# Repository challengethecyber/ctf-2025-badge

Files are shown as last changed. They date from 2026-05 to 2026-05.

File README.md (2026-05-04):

# ctf-2025-badge
Badge related files for CTC 2025 CTF

badge2025

## Info

- ESP32-C3-Mini
- Micropython
- E-ink display (GDEW0154M10) with UC8151 custom driver for quick partial refreshes
- IO expander (XL9535)
- EEPROM
- SAO

See schematics: [ctc_2025.pdf](hardware/ctc_2025.pdf)

## Credits

 - PCB hw design by [Max Grim](https://github.com/maxgrim).
 - Software by [c3c](https://github.com/c3c) and Max.
 - Display driver based on [GxEPD2](https://github.com/ZinggJM/GxEPD2).

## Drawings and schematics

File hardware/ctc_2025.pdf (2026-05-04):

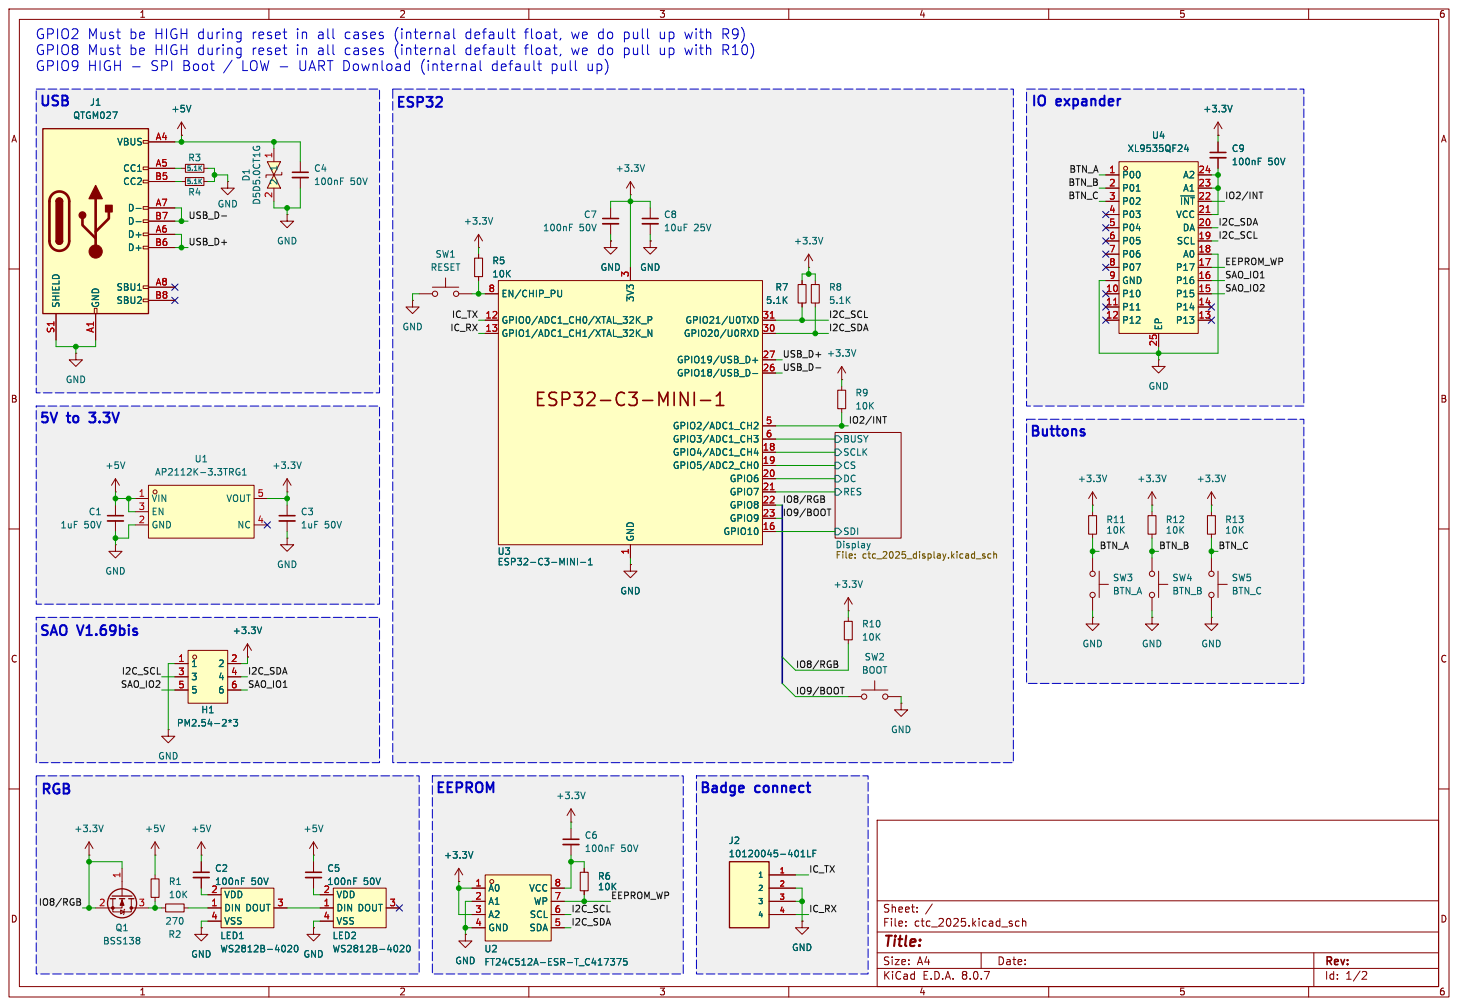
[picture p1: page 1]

SDI Display File: ctc_2025_display.kicad_sch GND

3 GPIO20/U0RXD 30 GPIO21/U0TXD 31 GPIO2/ADC1_CH2 5 GPIO3/ADC1_CH3 6 EN/CHIP_PU 8 U3ESP32-C3-MINI-1 GND GND

Id: 1/2 Title: File: ctc_2025.kicad_sch Sheet: /

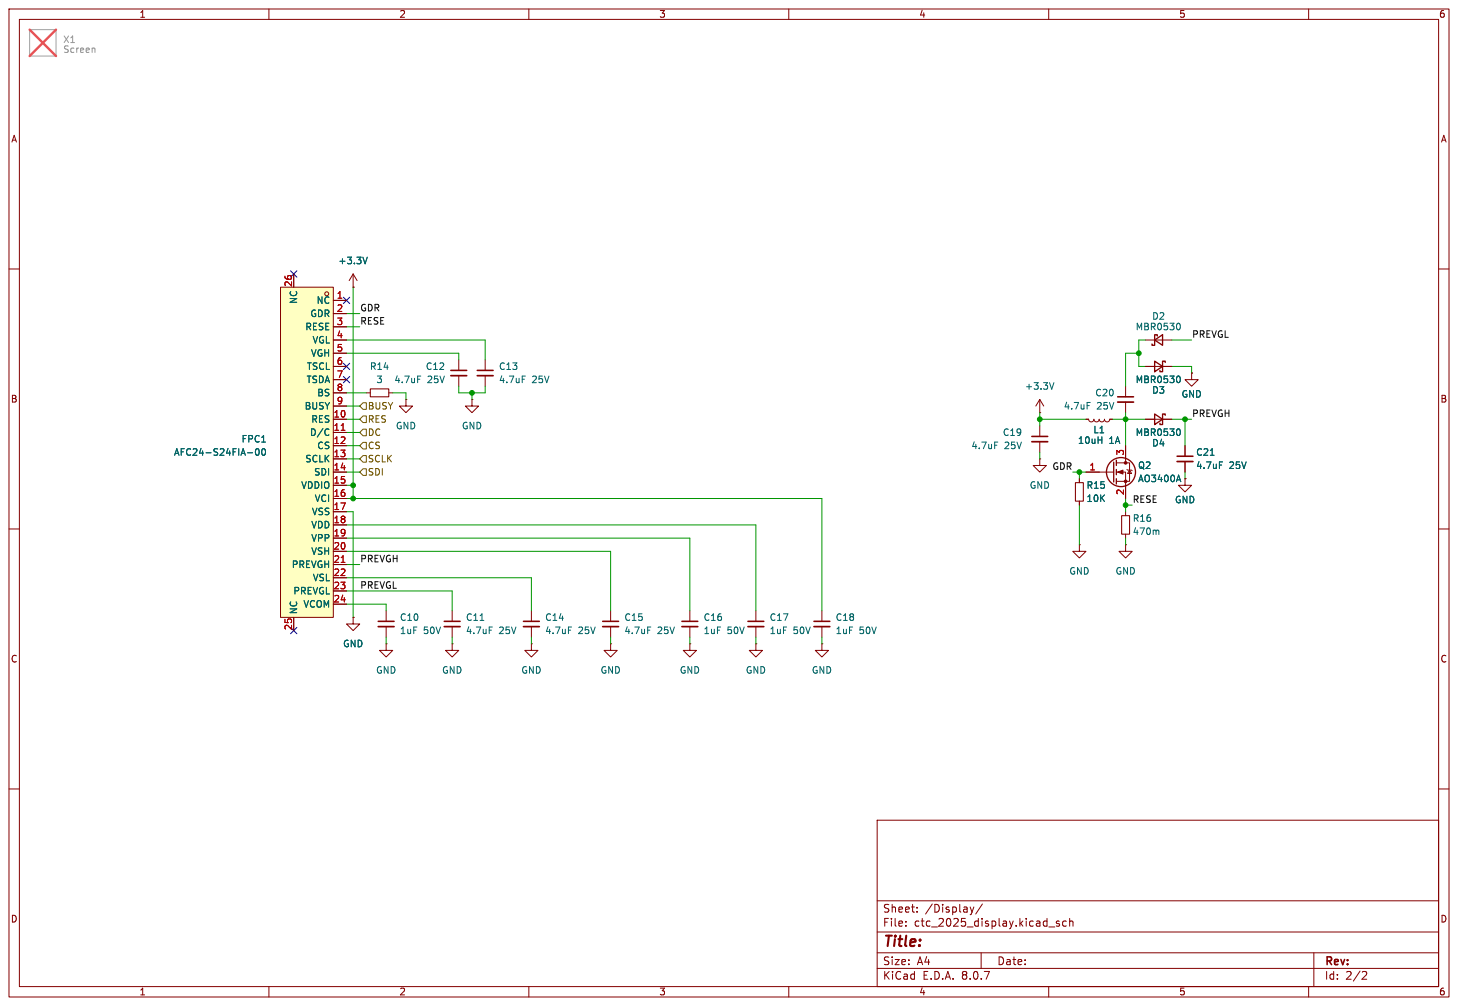
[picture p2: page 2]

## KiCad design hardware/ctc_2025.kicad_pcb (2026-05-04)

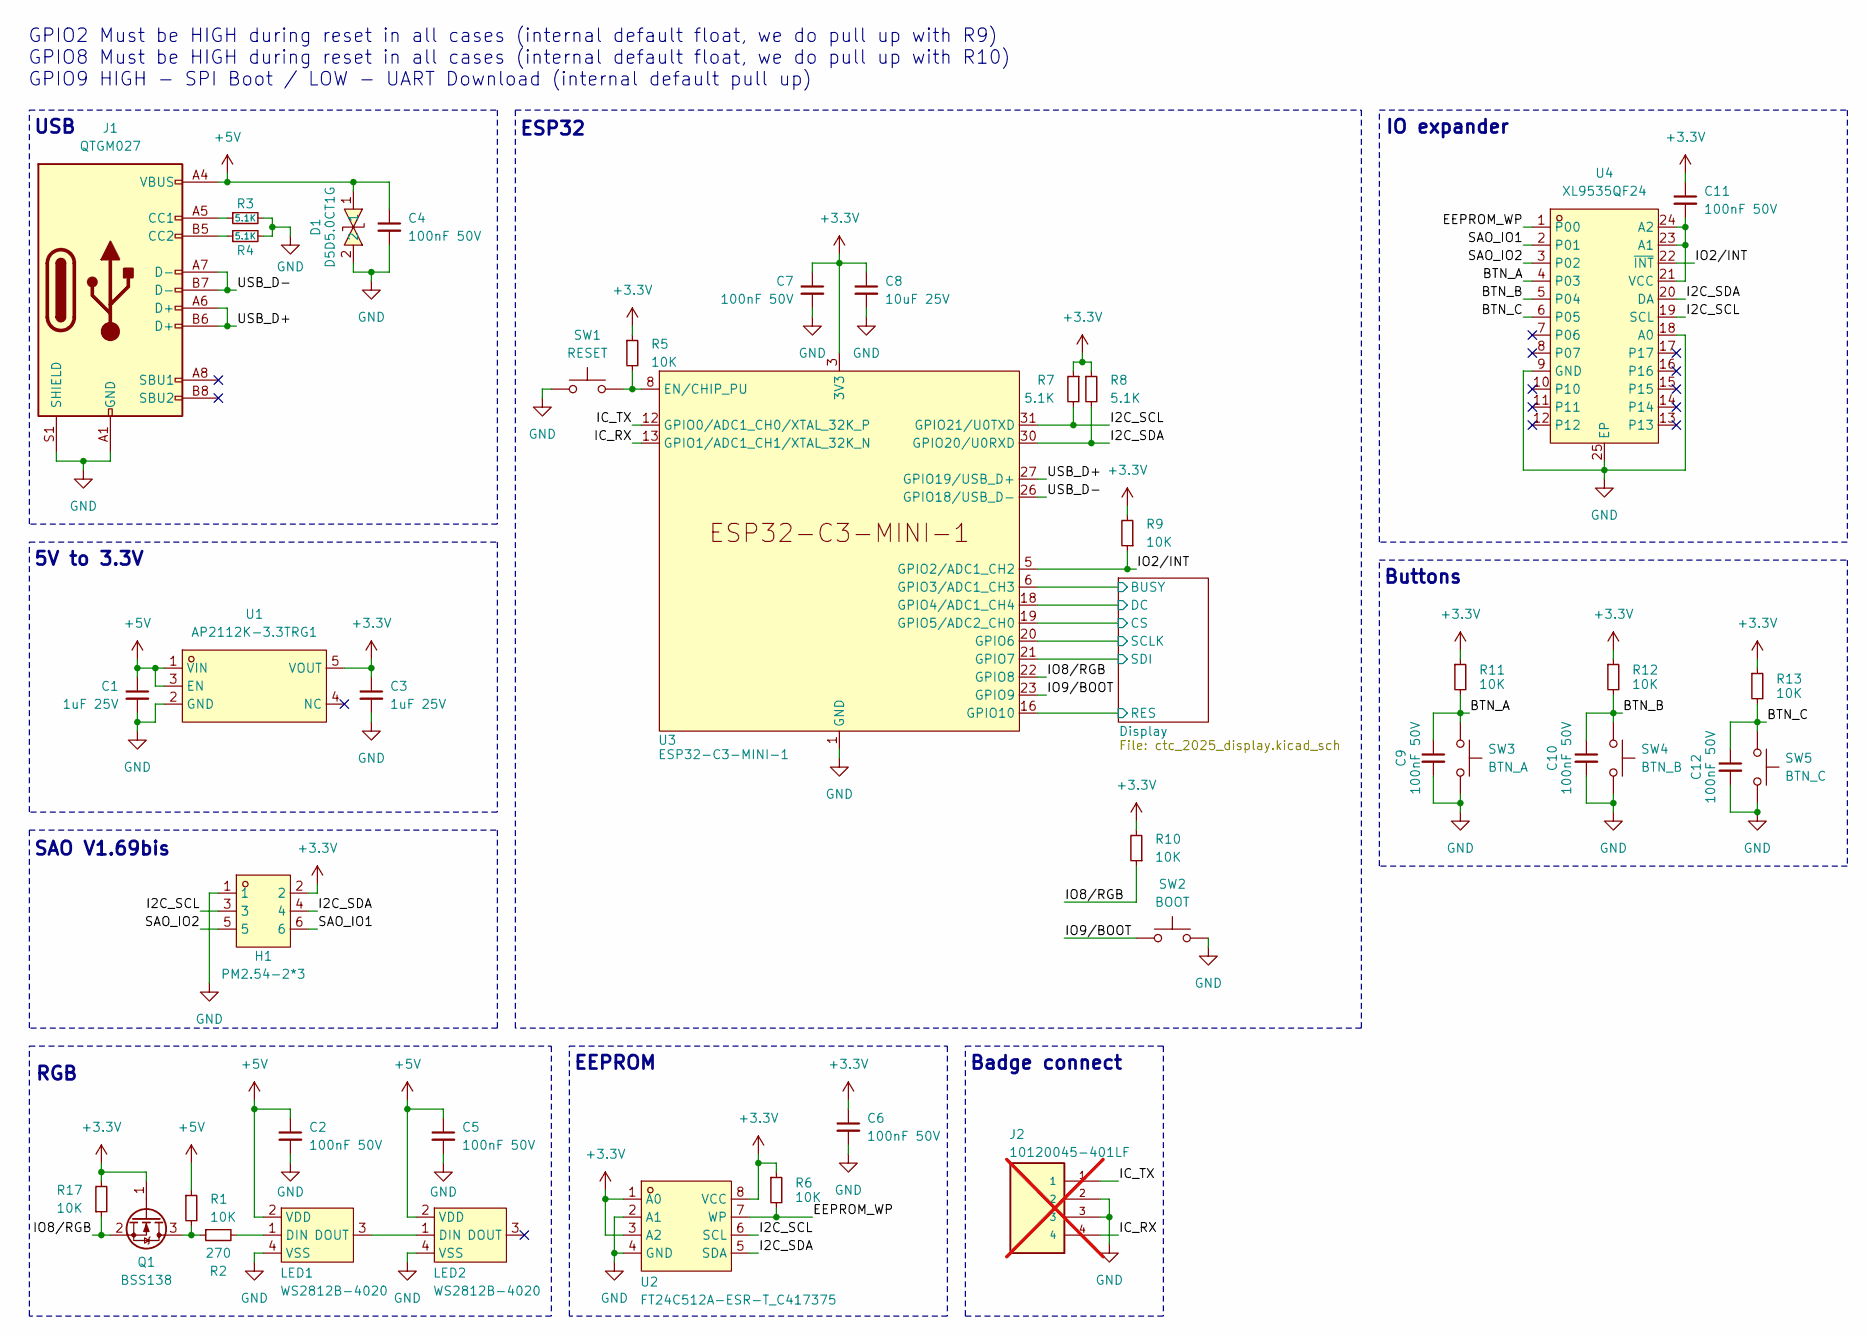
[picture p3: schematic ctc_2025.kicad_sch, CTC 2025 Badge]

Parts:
C1, C3: 1uF 25V; C_0402_1005Metric; LCSC Part C52923
C2, C4, C5, C6, C7, C9, C10, C11, C12: 100nF 50V; C_0402_1005Metric; LCSC Part C307331
C8: 10uF 25V; C_0603_1608Metric; LCSC Part C96446
D1: D5D5.0CT1G; SOD-523_L1.2-W0.8-LS1.6-BI; LCSC Part C383211
H1: PM2.54-2*3; HDR-TH_6P-P2.54-V-F-R2-C3-S2.54; LCSC Part C5116527
J1: QTGM027; USB-C-SMD_TYPE-C-16P-QTGM027-mod; LCSC Part C2681552
J2: 10120045-401LF; AMPHENOL_10120045-401LF; PARTREV B; not fitted
LED1, LED2: WS2812B-4020; LED-SMD_WS2812B-4020; LCSC Part C965557
Q1: BSS138; SOT-23; LCSC Part C426569
R1, R5, R6, R9, R10, R11, R12, R13, R17: 10K; R_0402_1005Metric; LCSC Part C25744
R2: 270; R_0402_1005Metric; LCSC Part C25155
R3, R4, R7, R8: 5.1K; R_0402_1005Metric; LCSC Part C25905
SW1: RESET; SW-SMD_4P-L4.2-W3.4-P2.15-LS5.2; LCSC Part C2888434
SW2: BOOT; SW-SMD_4P-L4.2-W3.4-P2.15-LS5.2; LCSC Part C2888434
SW3: BTN_A; KEY-SMD_1TS003B; LCSC Part C319395
SW4: BTN_B; KEY-SMD_1TS003B; LCSC Part C319395
SW5: BTN_C; KEY-SMD_1TS003B; LCSC Part C319395
U1: AP2112K-3.3TRG1; SOT-25-5_L2.9-W1.6-P0.95-LS2.8-BL; LCSC Part C51118
U2: FT24C512A-ESR-T_C417375; SOP-8_L4.9-W3.9-P1.27-LS6.0-BL; LCSC Part C417375
U3: ESP32-C3-MINI-1; LCSC Part C2838502
U4: XL9535QF24; QFN-24_L4.0-W4.0-P0.50-BL-EP2.6; LCSC Part C5444301

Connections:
+3.3V: C3.1, C6.1, C7.1, C8.1, C11.1, H1.2, Q1.1 (G), R5.1, R6.1, R7.1, R8.1, R9.2, R10.2, R11.1, R12.1, R13.1, R17.2, U1.5 (VOUT), U2.1 (A0), U2.3 (A2), U2.8 (VCC), U3.3 (3V3); also elsewhere on the board
/BTN_A: C9.1, R11.2, SW3.1, U4.4 (P03)
/BTN_B: C10.1, R12.2, SW4.1, U4.5 (P04)
/BTN_C: C12.1, R13.2, SW5.1, U4.6 (P05)
/Display/BUSY: U3.6 (GPIO3/ADC1_CH3); also elsewhere on the board
/Display/CS: U3.19 (GPIO5/ADC2_CH0); also elsewhere on the board
/Display/DC: U3.18 (GPIO4/ADC1_CH4); also elsewhere on the board
/Display/RES: U3.16 (GPIO10); also elsewhere on the board
/Display/SCLK: U3.20 (GPIO6); also elsewhere on the board
/Display/SDI: U3.21 (GPIO7); also elsewhere on the board
/EEPROM_WP: R6.2, U2.7 (WP), U4.1 (P00)
/I2C_SCL: H1.3, R7.2, U2.6 (SCL), U3.31 (GPIO21/U0TXD), U4.19 (SCL)
/I2C_SDA: H1.4, R8.2, U2.5 (SDA), U3.30 (GPIO20/U0RXD), U4.20 (DA)
/IC_RX: J2.4, U3.13 (GPIO1/ADC1_CH1/XTAL_32K_N)
/IC_TX: J2.1, U3.12 (GPIO0/ADC1_CH0/XTAL_32K_P)
/IO2/INT: R9.1, U3.5 (GPIO2/ADC1_CH2), U4.22 (~INT)
/IO8/RGB: Q1.2 (S), R10.1, R17.1, U3.22 (GPIO8)
/IO9/BOOT: SW2.1, SW2.2, U3.23 (GPIO9)
/SAO_IO1: H1.6, U4.2 (P01)
/SAO_IO2: H1.5, U4.3 (P02)
/USB_D+: J1.A6 (D+), J1.B6 (D+), U3.27 (GPIO19/USB_D+)
/USB_D-: J1.A7 (D-), J1.B7 (D-), U3.26 (GPIO18/USB_D-)
unnamed: J1.A5 (CC1), R3.1
unnamed: J1.B5 (CC2), R4.1
unnamed: LED1.1 (DIN), R2.2
unnamed: LED1.3 (DOUT), LED2.1 (DIN)
unnamed: Q1.3 (D), R1.2, R2.1
unnamed: R5.2, SW1.1, SW1.2, U3.8 (EN/CHIP_PU)
unnamed: C11.2, U4.21 (VCC), U4.23 (A1), U4.24 (A2)

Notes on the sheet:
USB
5V to 3.3V
ESP32
Buttons
RGB
SAO V1.69bis
EEPROM
Badge connect
IO expander
GPIO2 Must be HIGH during reset in all cases (internal default float, we do pull up with R9) GPIO8 Must be HIGH during reset in all cases (internal default float, we do pull up with R10) GPIO9 HIGH - SPI Boot / LOW - UART Download (internal default pull up)

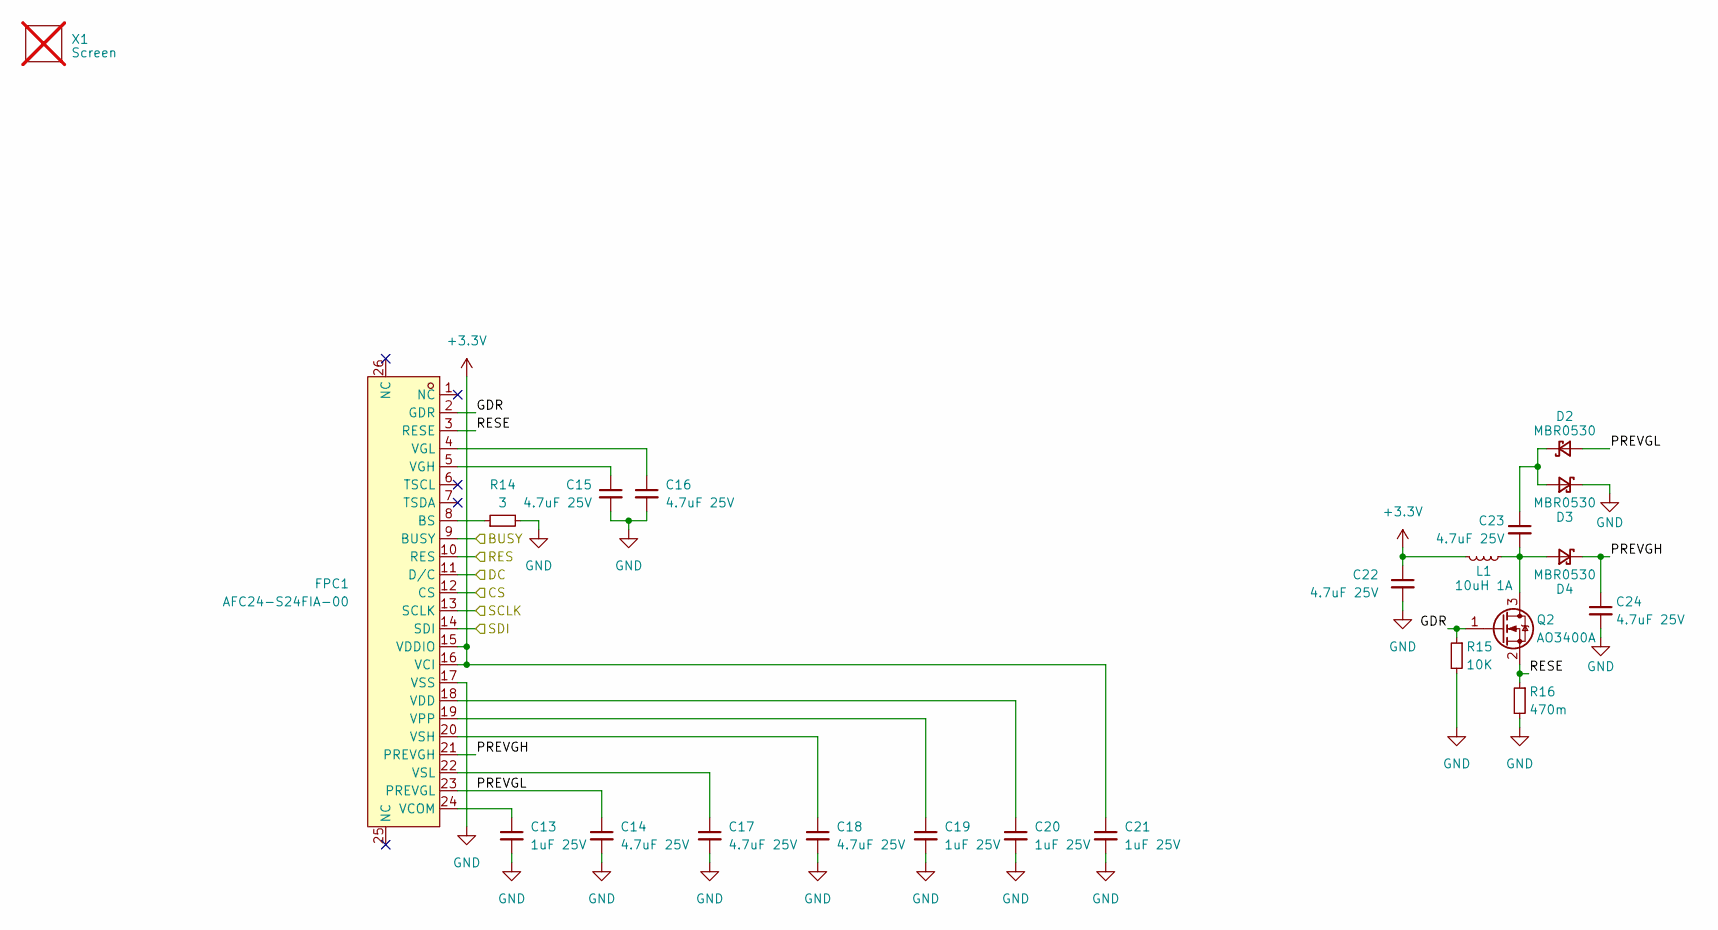
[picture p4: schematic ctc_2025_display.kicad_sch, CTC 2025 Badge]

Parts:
C13, C19, C20, C21: 1uF 25V; C_0402_1005Metric; LCSC Part C52923
C14, C15, C16, C17, C18, C22, C23, C24: 4.7uF 25V; C_0805_2012Metric; LCSC Part C1779
D2, D3, D4: MBR0530; D_SOD-123; LCSC Part C475718
FPC1: AFC24-S24FIA-00; FPC-SMD_P0.50-24P_QCHF-SM-H2.0-mod; LCSC Part C262683
L1: 10uH 1A; IND-SMD_L3.0-W3.0; LCSC Part C45405
Q2: AO3400A; SOT-23-3; LCSC Part C5224194
R14: 3; R_0402_1005Metric; LCSC Part C270411
R15: 10K; R_0402_1005Metric; LCSC Part C25744
R16: 470m; R_0402_1005Metric; LCSC Part C3017627
X1: Screen; not fitted

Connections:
+3.3V: C21.1, C22.1, FPC1.15 (VDDIO), FPC1.16 (VCI), L1.2; also elsewhere on the board
/Display/BUSY: FPC1.9 (BUSY); also elsewhere on the board
/Display/CS: FPC1.12 (CS); also elsewhere on the board
/Display/DC: FPC1.11 (D/C); also elsewhere on the board
/Display/GDR: FPC1.2 (GDR), Q2.1 (G), R15.1
/Display/PREVGH: C24.1, D4.1 (K), FPC1.21 (PREVGH)
/Display/PREVGL: C14.1, D2.2 (A), FPC1.23 (PREVGL)
/Display/RES: FPC1.10 (RES); also elsewhere on the board
/Display/RESE: FPC1.3 (RESE), Q2.2 (S), R16.1
/Display/SCLK: FPC1.13 (SCLK); also elsewhere on the board
/Display/SDI: FPC1.14 (SDI); also elsewhere on the board
unnamed: C23.1, D2.1 (K), D3.2 (A)
unnamed: C23.2, D4.2 (A), L1.1, Q2.3 (D)
unnamed: FPC1.8 (BS), R14.1
unnamed: C13.1, FPC1.24 (VCOM)
unnamed: C20.1, FPC1.18 (VDD)
unnamed: C15.1, FPC1.5 (VGH)
unnamed: C16.1, FPC1.4 (VGL)
unnamed: C19.1, FPC1.19 (VPP)
unnamed: C18.1, FPC1.20 (VSH)
unnamed: C17.1, FPC1.22 (VSL)

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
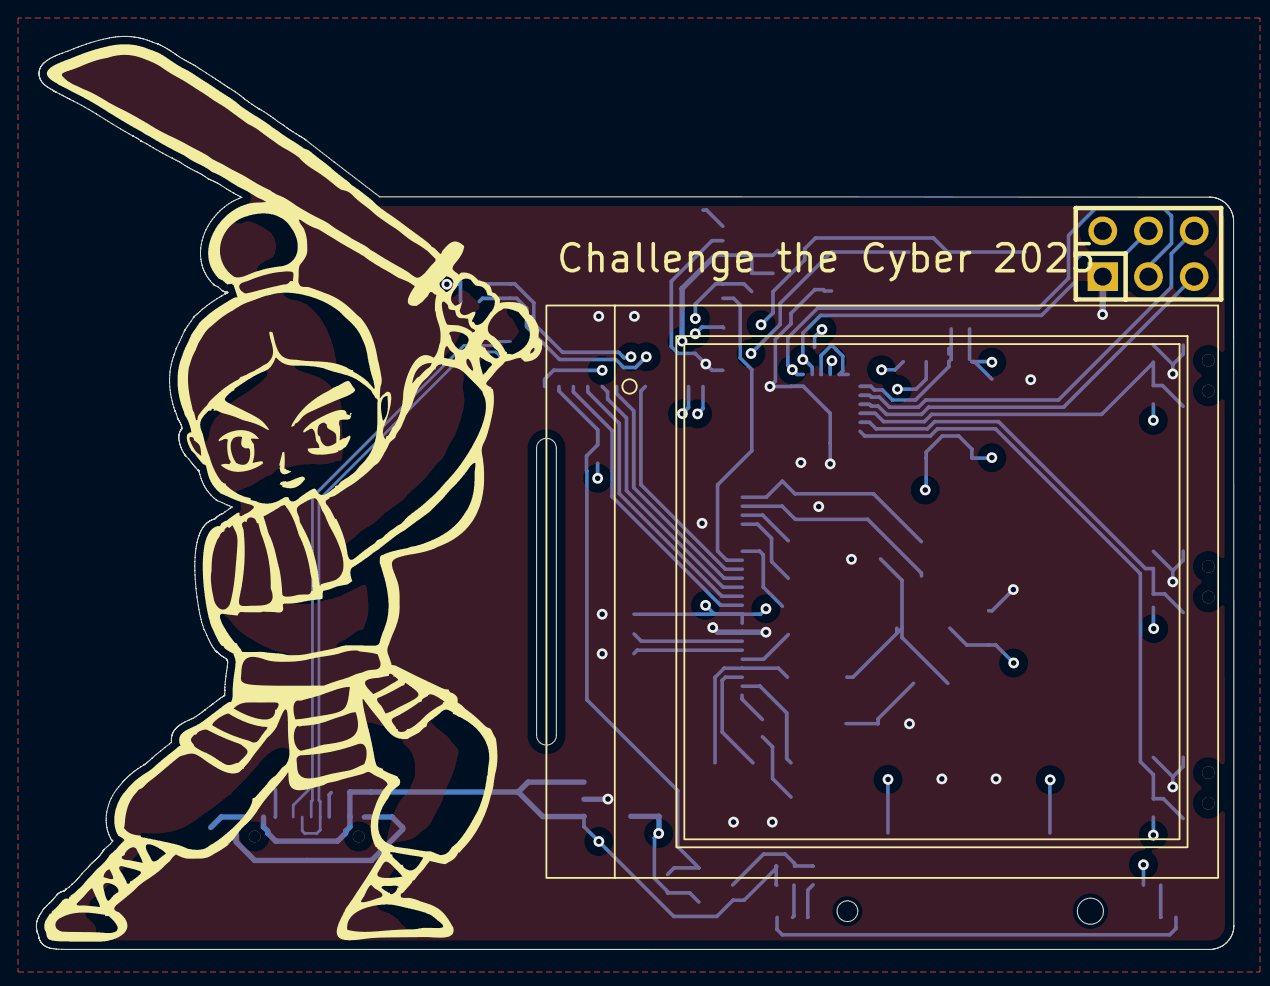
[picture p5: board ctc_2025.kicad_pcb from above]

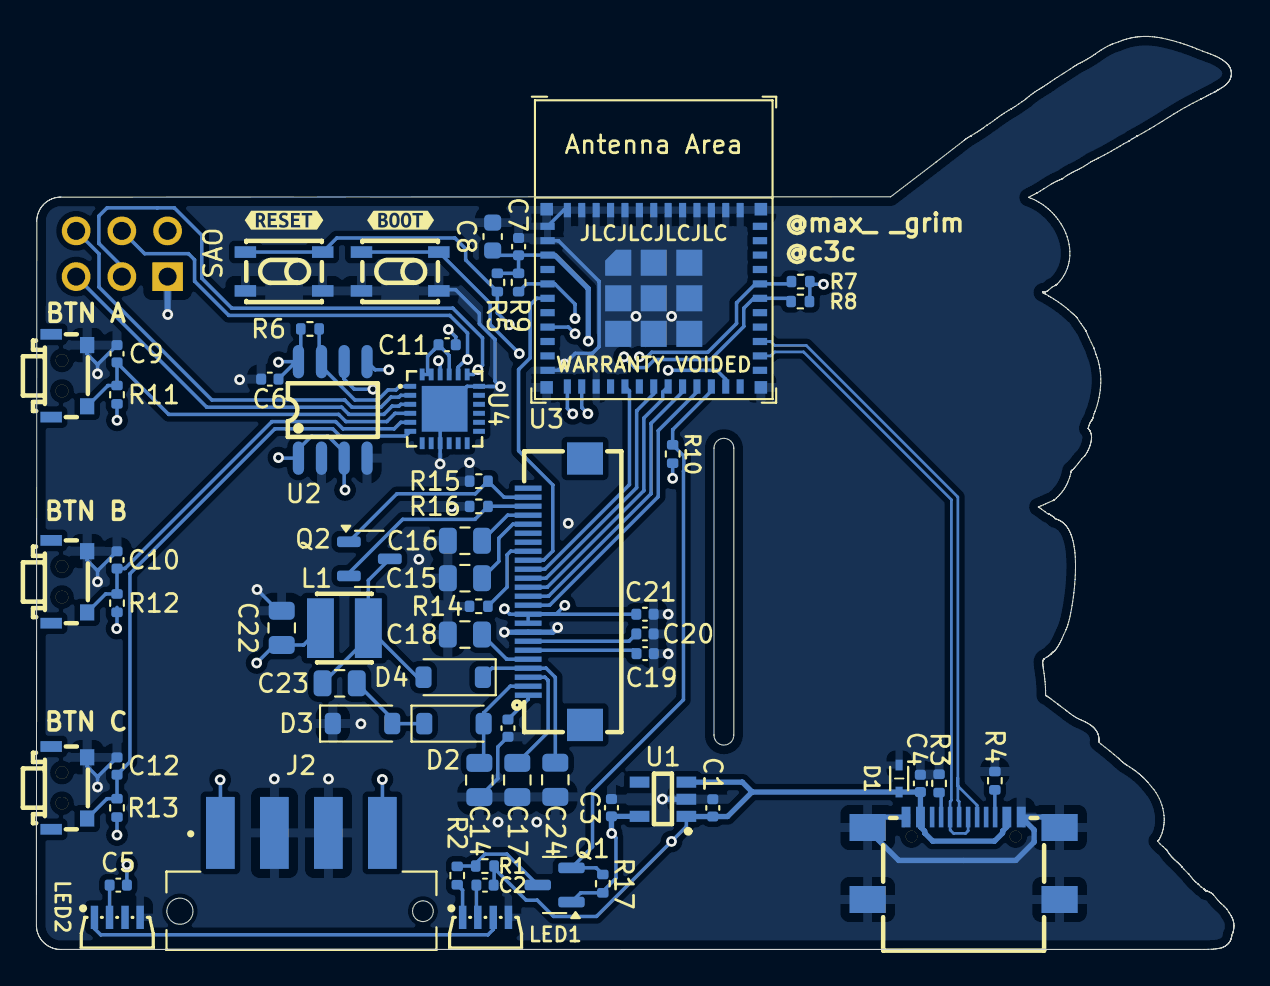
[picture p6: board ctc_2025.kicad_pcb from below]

Board: 4 copper layers, 66.5 x 50.7 mm, 66 parts (64 on the bottom side), 47 nets.

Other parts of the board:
kibuzzard-676D3FD4: G***; kibuzzard-676D3FD4
kibuzzard-676D3FEC: G***; kibuzzard-676D3FEC

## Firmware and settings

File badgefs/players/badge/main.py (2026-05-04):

import gc
gc.enable()

import micropython
micropython.alloc_emergency_exception_buf(100)

import asyncio
import machine
import neopixel
import ntptime
import sys
import expanderbutton
import textwriter
import uc8151

from .utils import get_team_id, get_darkmode, load_fonts, make_image, print_output

# Apps
from .nametag import Nametag

# Tasks
from .menu import task_menu
from .rolodex import task_serial_send

BENCHMARK = micropython.const(True)
DEBUG = micropython.const(False)

BUTTON_EXPANDER_I2C_ADDRESS = micropython.const(0x26)
BUTTON_EXPANDER_PIN = micropython.const(2)

EINK_CS_PIN = micropython.const(5)
EINK_DC_PIN = micropython.const(4)
EINK_RST_PIN = micropython.const(10)
EINK_BUSY_PIN = micropython.const(3)
EINK_SCK_PIN = micropython.const(6)
EINK_MOSI_PIN = micropython.const(7)
EINK_SPEED = micropython.const(4)

I2C_SDA_PIN = micropython.const(20)
I2C_SCL_PIN = micropython.const(21)

NEOPIXELS_PIN = micropython.const(8)

SERIAL_TX_PIN = micropython.const(0)
SERIAL_RX_PIN = micropython.const(1)

_fonts_regular = load_fonts("hack")
_fonts_bold = load_fonts("hackbold")

async def _async_exception_handler(eink, exception):
    eink.fb.fill(0)

    text_writer = textwriter.TextWriter(eink, _fonts_regular, _fonts_bold)
    current_y = 0

    smiley_font = _fonts_bold[36]
    text_font = _fonts_regular[16]

    text_writer.write_text_center(":(", smiley_font, current_y)
    current_y += smiley_font.height + 10

    text_font = _fonts_regular[16]
    text_writer.write_text("Your badge ran", text_font, 0, current_y)
    current_y += text_font.height
    text_writer.write_text("into a problem", text_font, 0, current_y)
    current_y += text_font.height
    text_writer.write_text("and needs to", text_font, 0, current_y)
    current_y += text_font.height
    text_writer.write_text("restart.", text_font, 0, current_y)
    current_y += text_font.height*2
    
    if isinstance(exception, expanderbutton.ExpanderButtonException):
        text_font = _fonts_regular[14]
        text_writer.write_text("Try another USB port.", text_font, 0, current_y)
        current_y += text_font.height

    await eink.display()
    await asyncio.sleep(2)

    machine.reset()


def _exception_handler(_, context):
    sys.print_exception(context["exception"])

    eink = _setup_eink_screen()
    new_loop = asyncio.new_event_loop()
    new_loop.run_until_complete(_async_exception_handler(eink=eink, exception=context["exception"]))
    

def _setup_eink_screen():
    return uc8151.UC8151(
        spi=machine.SPI(
            1,
            baudrate=20000000,
            phase=0,
            polarity=0,
            sck=EINK_SCK_PIN,
            mosi=EINK_MOSI_PIN,
        ),
        cs=EINK_CS_PIN,
        dc=EINK_DC_PIN,
        rst=EINK_RST_PIN,
        busy=EINK_BUSY_PIN,
        darkmode=get_darkmode(),
    )


def _setup_button_expander():
    buttons = [
        {
            "bit": 3,
            "cb_short": lambda: expanderbutton.ButtonPress.handle_press(
                expanderbutton.ButtonPress.BUTTON_ENTER, expanderbutton.ButtonPress.SHORT
            ),
            "cb_long": lambda: expanderbutton.ButtonPress.handle_press(
                expanderbutton.ButtonPress.BUTTON_ENTER, expanderbutton.ButtonPress.LONG
            ),
        },
        {
            "bit": 4,
            "cb_short": lambda: expanderbutton.ButtonPress.handle_press(
                expanderbutton.ButtonPress.BUTTON_UP, expanderbutton.ButtonPress.SHORT
            ),
            "cb_long": lambda: expanderbutton.ButtonPress.handle_press(
                expanderbutton.ButtonPress.BUTTON_UP, expanderbutton.ButtonPress.LONG
            ),
        },
        {
            "bit": 5,
            "cb_short": lambda: expanderbutton.ButtonPress.handle_press(
                expanderbutton.ButtonPress.BUTTON_DOWN, expanderbutton.ButtonPress.SHORT
            ),
            "cb_long": lambda: expanderbutton.ButtonPress.handle_press(
                expanderbutton.ButtonPress.BUTTON_DOWN, expanderbutton.ButtonPress.LONG
            ),
        },
    ]

    try:
        i2c = machine.I2C(0, scl=machine.Pin(I2C_SCL_PIN), sda=machine.Pin(I2C_SDA_PIN))
        irq_pin = machine.Pin(BUTTON_EXPANDER_PIN, machine.Pin.IN, None)
        button_expander = expanderbutton.uButtonExpander(i2c, BUTTON_EXPANDER_I2C_ADDRESS, irq_pin, buttons)
    except Exception as e:
        _exception_handler(None, {"exception": expanderbutton.ExpanderButtonException("There seems to be a hardware issue. Try another USB port.")})
    
    return button_expander


def _setup_uart_serial():
    uart = machine.UART(
        1,
        baudrate=9600,
        bits=8,
        stop=1,
        parity=0,
        tx=machine.Pin(SERIAL_TX_PIN, machine.Pin.OUT),
        rx=machine.Pin(SERIAL_RX_PIN, machine.Pin.IN),
    )
    return uart


def startup():
    async def _task_gc_collect():
        while True:
            gc.collect()
            await asyncio.sleep(1)

    async def _task_boot(eink):
        _textwriter = textwriter.TextWriter(eink, _fonts_regular, _fonts_bold)

        theme_font = _fonts_bold[16]
        _textwriter.write_text_center("Security Samurai", theme_font, 35)

        eink.fb.blit(make_image("ctc2025", 126, 18), 13, 10)
        eink.fb.blit(make_image("ctcicon", 54, 53), 49, 65)
        
        try:
            eink.fb.blit(make_image(f"team{get_team_id()}", 152, 32), 0, 151-32)
        except:
            eink.fb.blit(make_image("flowers", 152, 16), 0, 151-16)
        
        _textwriter.write_text_center("Security Samurai", theme_font, 35)
        
        await eink.display()
        await asyncio.sleep(0.5)
        
    # fmt: off
    print("""
 _____                                                                _____ 
( ___ )                                                              ( ___ )
 |   |~~~~~~~~~~~~~~~~~~~~~~~~~~~~~~~~~~~~~~~~~~~~~~~~~~~~~~~~~~~~~~~~|   | 
 |   |  ██████╗████████╗ ██████╗    ██████╗  ██████╗ ██████╗ ███████╗ |   | 
 |   | ██╔════╝╚══██╔══╝██╔════╝    ╚════██╗██╔═████╗╚════██╗██╔════╝ |   | 
 |   | ██║        ██║   ██║          █████╔╝██║██╔██║ █████╔╝███████╗ |   | 
 |   | ██║        ██║   ██║         ██╔═══╝ ████╔╝██║██╔═══╝ ╚════██║ |   | 
 |   | ╚██████╗   ██║   ╚██████╗    ███████╗╚██████╔╝███████╗███████║ |   | 
 |   |  ╚═════╝   ╚═╝    ╚═════╝    ╚══════╝ ╚═════╝ ╚══════╝╚══════╝ |   |
 |   |                     ~~ SECURITY SAMURAIS ~~                    |   |  
 |___|~~~~~~~~~~~~~~~~~~~~~~~~~~~~~~~~~~~~~~~~~~~~~~~~~~~~~~~~~~~~~~~~|___| 
(_____)                                                              (_____)
""")

    print("")
    # fmt: on

    button_expander = _setup_button_expander()

    eink = _setup_eink_screen()
    uart = _setup_uart_serial()

    loop = asyncio.get_event_loop()
    _ = loop.create_task(_task_gc_collect())

    _ = loop.create_task(button_expander.run())
    boot_promise = loop.create_task(_task_boot(eink))
    _ = loop.create_task(task_menu(boot_promise, eink, uart))
    _ = loop.create_task(task_serial_send(uart))

    loop.set_exception_handler(_exception_handler)
    loop.run_forever()

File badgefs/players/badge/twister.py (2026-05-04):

# A mersenne twister implementation for betting systems.
# Very secure

class MiniMT27:

    def __init__(self, seed=3):
        self.w = 7
        self.n = 3
        self.m = 3
        self.r = 3
        self.a = 72
        self.u = 1
        self.d = 9
        self.s = 5
        self.b = 66
        self.t = 5
        self.c = 81
        self.l = 5
        self.f = 5

        self.mask = (1 << self.w) - 1
        self.lower_mask = (1 << self.r) - 1
        self.upper_mask = ((~self.lower_mask) & self.mask)

        self.state = [0]*self.n
        self.index = self.n  # will force a twist on first use
        self.seed_mt(seed)

    def seed_mt(self, seed):
        self.state[0] = seed & self.mask
        for i in range(1, self.n):
            x = (self.f * (self.state[i-1] ^ (self.state[i-1] >> (self.w - 2))) + i)
            self.state[i] = x & self.mask

    def twist(self):
        for i in range(self.n):
            x = (self.state[i] & self.upper_mask) \
                + (self.state[(i+1) % self.n] & self.lower_mask)
            xA = x >> 1
            if (x & 1) == 1:
                xA ^= self.a
            self.state[i] = xA & self.mask
        self.index = 0

    def rand(self):
        if self.index >= self.n:
            self.twist()
        y = self.state[self.index]

        # Temper
        y ^= (y >> self.u) & self.d
        y ^= (y << self.s) & self.b
        y ^= (y << self.t) & self.c
        y ^= (y >> self.l)

        self.index += 1
        return y & self.mask

    def random_dice(self):
        """
        Example: Return a value in [1..6] using the internal cycle.
        """
        return (self.rand() % 6) + 1


if __name__ == "__main__":
    cycle = 27

    for seed in range(20):
        print("[+] MiniMT27 seed:", seed)
        mt = MiniMT27(seed=seed)

        results = []
        for i in range(cycle * 3):
            results.append(mt.random_dice())

        print("Cycle 1:", results[:cycle])
        print("Cycle 2:", results[cycle:cycle*2])
        print("Cycle 3:", results[cycle*2:])
        print()
